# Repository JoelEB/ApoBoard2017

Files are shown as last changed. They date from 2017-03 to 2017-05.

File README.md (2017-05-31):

2017 Propagand-Eye
=======================================
<p align="center">

</p>

This is the development repo for the 2017 Apogaea soldering Workshop project, the Propagand-Eye. 

For all final files for tutorials on how to hack your eyeball, please visit [https://github.com/apoboard](https://github.com/apoboard). 

To donate to this project, please send donations to joeleb on Venmo. 

This board uses an Atmega328p microcontroller (the same device in the Arduino Uno) and can be programmed with an FTDI serial adapter and the Arduino IDE. There is a DC/DC boost-converter (the PAM2401) to provide 5 volts from a single AA battery. On board are 10 addressable WS2812 LEDs (the same LEDs used on all Neopixel products). There is also an infrared (IR) transmitter/receiver pair that allows the boards to communicate with one another. A tactile button is also provided to switch through modes.

License Information
-------------------

All of these files are developed for free, for Apogaea, and for fun. It is publicly available under the GNU General Public License version 2 (the "GPL License"). For more information, please see: http://www.gnu.org/licenses/gpl-2.0.html

Copyright (c) John English, Joel Bartlett, 2017 Licensing: GPL v2

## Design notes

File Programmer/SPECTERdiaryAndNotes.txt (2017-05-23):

getting avrisp mkii working in kali-linux:

copy these rules to a new /etc/udev/avrisp.rules:
SUBSYSTEM!="usb", ACTION!="add", GOTO="avrisp_end"

# Atmel Corp. JTAG ICE mkII
ATTR{idVendor}=="03eb", ATTR{idProduct}=="2103", MODE="660", GROUP="dialout"
# Atmel Corp. AVRISP mkII
ATTR{idVendor}=="03eb", ATTR{idProduct}=="2104", MODE="660", GROUP="dialout"
# Atmel Corp. Dragon
ATTR{idVendor}=="03eb", ATTR{idProduct}=="2107", MODE="660", GROUP="dialout"

LABEL="avrisp_end"

i used nano to do this
root@xfinitywifi:~# nano /etc/udev/avrisp.rules
root@xfinitywifi:~# cd /etc/udev/rules.d/
root@xfinitywifi:/etc/udev/rules.d# ln ../avrisp.rules 60-avrisp.rules
root@xfinitywifi:/etc/udev/rules.d# groups
root
root@xfinitywifi:/etc/udev/rules.d# service udev restart

failed

tried:
apt-get install uisp

and changing SYSFS too ATTR... no that was fine nvm

used this for debugging:
avrdude -c avrispmkII -P usb -p m328 -B 100 -v
ls -lrt /dev/*
dmesg | tail

okay got it to work when I also applied power @ ftdi at same time.
does power have to be provided seperately from avrisp?  That seems silly.
maybe theres an option to turn power pin on.
anyway... i did successfully read the eeprom using:
avrdude -c avrispmkII -P usb -p m328  -U eeprom:r:eepromtestread.hex:i -v -F

now to script it.
i found one python wrapper on github :-)  with a single contributor :-(
https://github.com/theterg/autoavrdude
this is pretty crude shell-parsing stuff... as the author admits.

here's the code:
from subprocess import Popen, PIPE
import threading
import fcntl
import os
import Queue

def setNonBlocking(fd):
    """
    Set the file description of the given file descriptor to non-blocking.
    """
    flags = fcntl.fcntl(fd, fcntl.F_GETFL)
    flags = flags | os.O_NONBLOCK
    fcntl.fcntl(fd, fcntl.F_SETFL, flags)

def reader(fd, queue):
    while True:
        try:
            data = fd.read()
            queue.put(data)
        except IOError:
            continue
        except Exception:
            return

def flushAndWrite(msg, p):
    p.stdout.flush()
    p.stderr.flush()
    p.stdin.write(msg)
    p.stdin.flush()

def writeAndReadResponse(msg, infd, outfd):
    outfd.flush()
    infd.write(msg)
    infd.flush()
    while True:
        try:
            return outfd.read()
        except IOError:
            continue
        except KeyboardInterrupt:
            return ''

def getVtarget(msg):
    lines = msg.split('\n')
    for line in lines:
        if line.startswith('Vtarget'):
            return float(line.split(':')[1][:-2])
    return 0.0

p = Popen("avrdude -c avrispmkii -p m328p -P usb -F -t", shell=True, stdin=PIPE, stdout=PIPE, stderr=PIPE)
setNonBlocking(p.stdout)
setNonBlocking(p.stderr)

#outqueue = Queue.Queue()
#errqueue = Queue.Queue()
#
#outthread = threading.Thread(target=reader, args=(p.stdout, outqueue))
#errthread = threading.Thread(target=reader, args=(p.stderr, errqueue))
#
#outthread.start()
#errthread.start()

*********************** NOTES ABOUT ATMEGA328 FUSES
from the datasheet:
Extended Fuse Byte for ATmega328/328P
Extended Fuse Byte	Bit No	Description				Default Value
BODLEVEL2(1)		2	Brown-out Detector trigger level	1 (unprogrammed)
BODLEVEL1(1)		1	Brown-out Detector trigger level	1 (unprogrammed)
BODLEVEL0(1)		0	Brown-out Detector trigger level	1 (unprogrammed)

High Fuse Byte for ATmega328/328P
High Fuse Byte		Bit No	Description				Default Value
RSTDISBL		7	External Reset Disable			1 (unprogrammed)
DWEN			6	debugWIRE Enable			1 (unprogrammed)
SPIEN			5	Enable Serial Program and Data Download	0 (programmed, SPI programming enabled)
WDTON			4	Watchdog Timer Always On		1 (unprogrammed)
EESAVE			3	EEPROM memory is preserved on erase	1 (unprogrammed), EEPROM not reserved
BOOTSZ1			2	Select Boot Size 			0 (programmed)
BOOTSZ0			1	Select Boot Size			0 (programmed)
BOOTRST			0	Select Reset Vector			1 (unprogrammed)

Low Fuse Byte for ATmega328/328P
Low Fuse Byte		Bit No	Description				Default Value
CKDIV8			7	Divide clock by 8			0 (programmed)
CKOUT			6	Clock output				1 (unprogrammed)
SUT1			5	Select start-up time			1 (unprogrammed)
SUT0			4	Select start-up time			0 (programmed)
CKSEL3			3	Select Clock source			0 (programmed)
CKSEL2			2	Select Clock source			0 (programmed)
CKSEL1			1	Select Clock source			1 (unprogrammed)
CKSEL0			0	Select Clock source			0 (programmed)

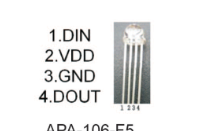
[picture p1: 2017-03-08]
WS2812_LED_Pinout.png

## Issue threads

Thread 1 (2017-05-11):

add A4 or A5 blink in final version of code for pogobed verification

JoelEB, 2017-05-11:
add A4 or A5 blink in final version of code for pogobed verification when programming

spec7er, 2017-05-15:
what code is watching A4/A5?? or is it an LED?  How should it blink? Continuously? Blink once?

JoelEB, 2017-05-15:
I can add this, but I just have a regular LED attached to pin A5 that will blink a few times in setup() to verify the code made it on. But I also added an addressable LED, so we could just use that to see if if starts blinking (each will be random, since the animations will be randomized).

JoelEB, 2017-05-28:
Added 5/28

Closed 2017-05-28.

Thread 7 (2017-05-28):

Error using programmerPi to write_flash

JoelEB, 2017-05-28:
pulled latest. Tested pogo bed on mac using Arduino IDE to burn bootloader and upload test sketch. Verified that all hardware works. Tried on raspberry pi and get this error:
```ApoCmd: write_flash```
```No ATMEGA328 connected```

spec7er, 2017-05-29:
run as root

Closed 2017-05-29.

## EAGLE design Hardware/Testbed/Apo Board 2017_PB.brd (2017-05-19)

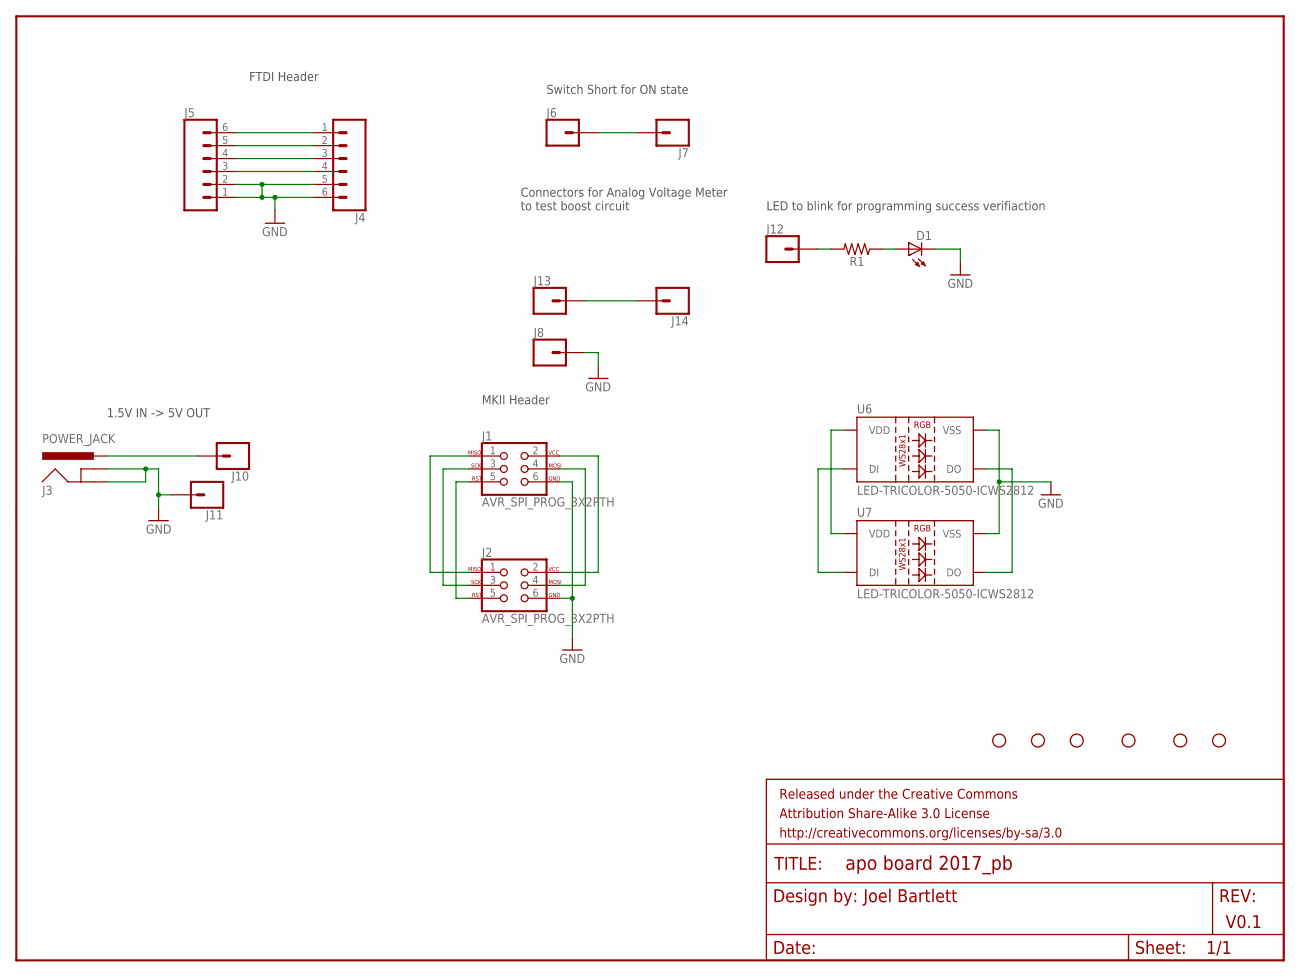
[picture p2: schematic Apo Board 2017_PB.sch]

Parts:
D1: LED5MM
FRAME1: FRAME-LETTER; CREATIVE_COMMONS
H1, H2, H3, H4, H5, H6: STAND-OFF
J1, J2: AVR_SPI_PROG_3X2PTH; 2X3
J3: POWER_JACK; POWER_JACK_PTH
J4, J5: CONN_06LONGPADS; 1X06_LONGPADS
J6, J7, J8, J10, J11, J12, J13, J14: CONN_01PTH_LONGPAD; 1X01_LONGPAD
R1: AXIAL-0.3-KIT
U6, U7: LED-TRICOLOR-5050-ICWS2812; LED-WS2812-THRU

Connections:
GND: D1.K (C), J1.6, J2.6, J3.GND, J3.GNDBREAK, J4.5, J4.6, J5.1, J5.2, J8.1, J11.1, U6.3 (VSS), U7.3 (VSS)
unnamed: J3.PWR, J10.1
unnamed: J1.4, J2.4
unnamed: J1.2, J2.2
unnamed: J1.5, J2.5
unnamed: J1.3, J2.3
unnamed: J1.1, J2.1
unnamed: U6.4 (DO), U7.4 (DO)
unnamed: J4.4, J5.3
unnamed: J4.3, J5.4
unnamed: J4.2, J5.5
unnamed: J4.1, J5.6
unnamed: J6.1, J7.1
unnamed: D1.A, R1.P$1 (1)
unnamed: J12.1, R1.P$2 (2)
unnamed: U6.1 (DI), U7.1 (DI)
unnamed: J13.1, J14.1
unnamed: U6.2 (VDD), U7.2 (VDD)

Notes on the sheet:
Joel Bartlett
V0.1
Switch Short for ON state
FTDI Header
1.5V IN -> 5V OUT
MKII Header
Connectors for Analog Voltage Meter to test boost circuit
LED to blink for programming success verifiaction

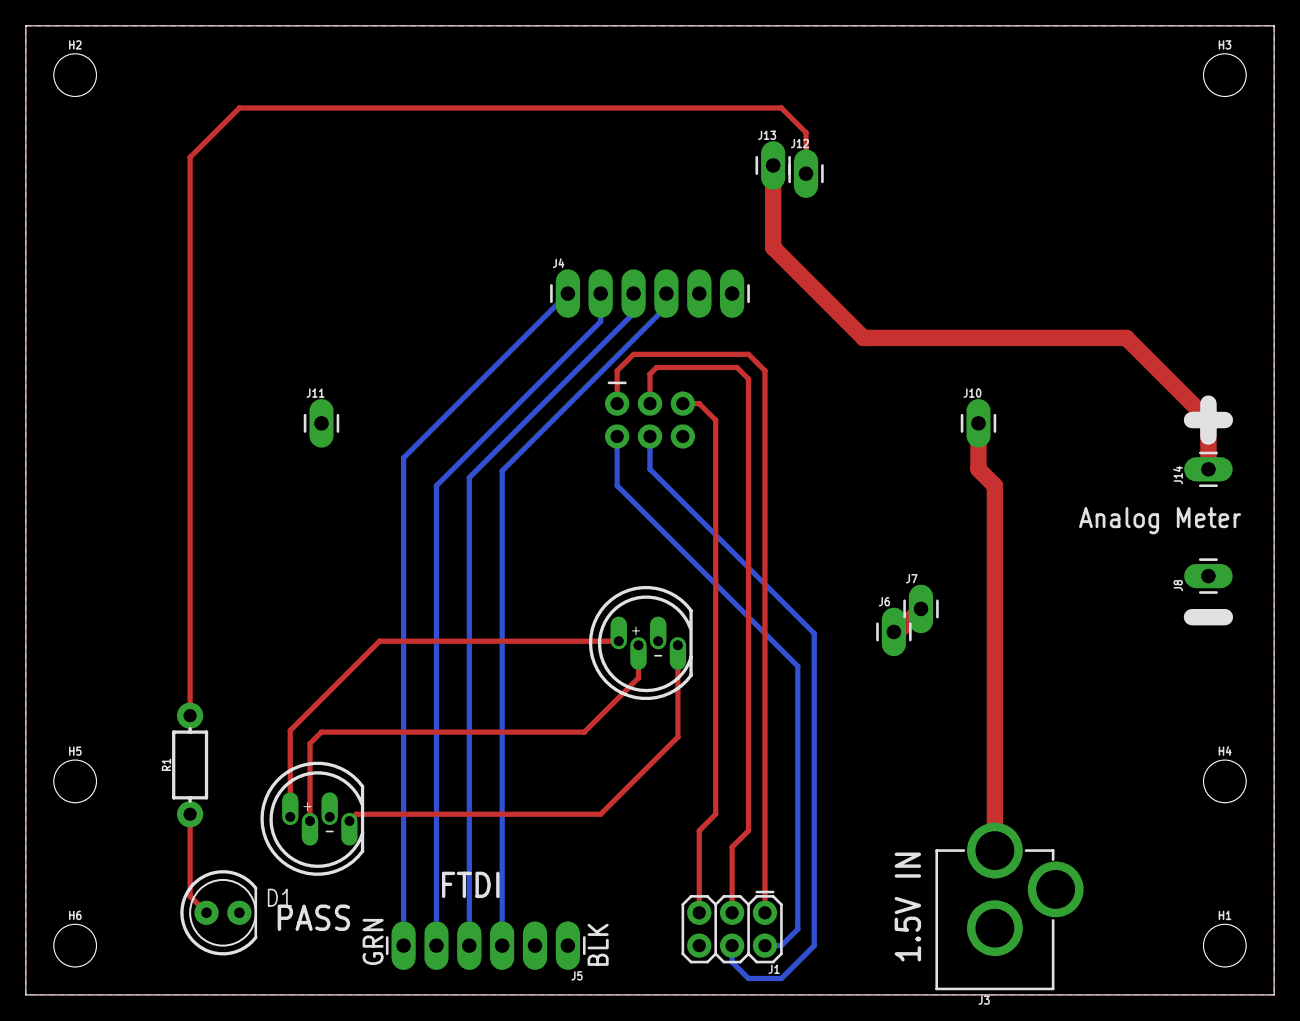
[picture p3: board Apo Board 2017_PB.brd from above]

Board: 2 copper layers, 96.5 x 74.9 mm, 24 parts (1 on the bottom side), 18 nets.

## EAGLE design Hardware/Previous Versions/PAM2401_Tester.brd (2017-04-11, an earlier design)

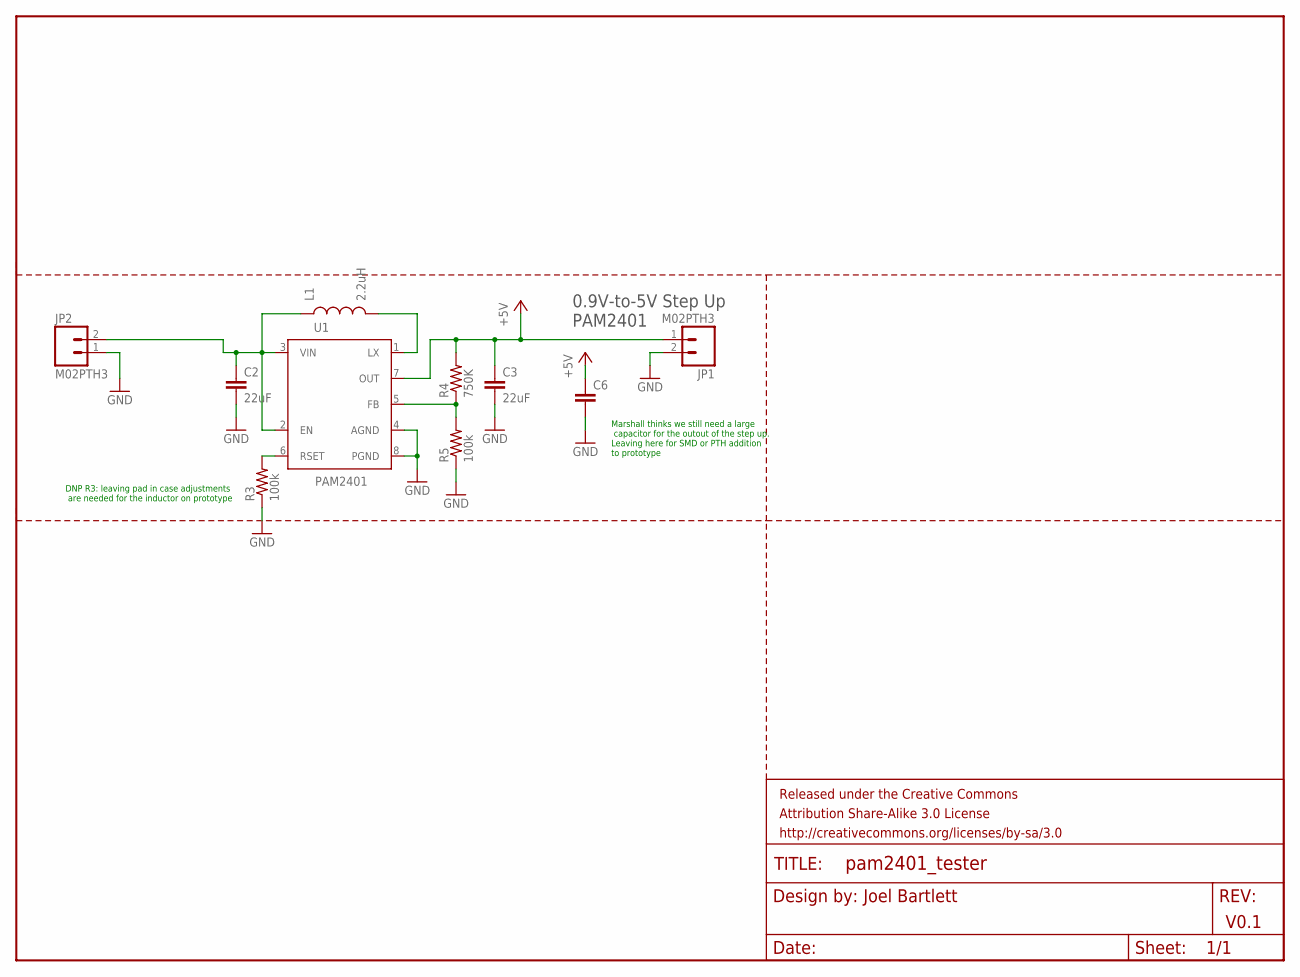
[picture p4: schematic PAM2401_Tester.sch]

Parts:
C2, C3: 22uF; 0805
C6: CAP1206; 1206
FRAME1: FRAME-LETTER; CREATIVE_COMMONS
JP1, JP2: M02PTH3; 1X02_LONGPADS
L1: 2.2uH; CR54
R3, R5: 100k; 0603-RES
R4: 750K; 0603-RES
U1: PAM2401; MSOP8

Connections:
+5V: C3.1, C6.1, JP1.1, R4.2, U1.7 (OUT)
+BATT_RAW: C2.1, JP2.2, L1.P$1 (1), U1.2 (EN), U1.3 (VIN)
GND: C2.2, C3.2, C6.2, JP1.2, JP2.1, R3.1, R5.1, U1.4 (AGND), U1.8 (PGND)
unnamed: R3.2, U1.6 (RSET)
unnamed: L1.P$2 (2), U1.1 (LX)
unnamed: R4.1, R5.2, U1.5 (FB)

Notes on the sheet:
Joel Bartlett
0.9V-to-5V Step Up PAM2401
DNP R3: leaving pad in case adjustments are needed for the inductor on prototype
Marshall thinks we still need a large capacitor for the outout of the step up. Leaving here for SMD or PTH addition to prototype
V0.1

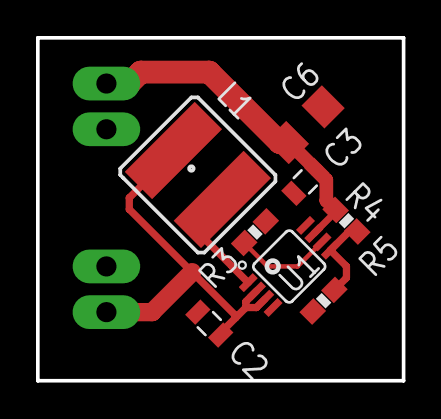
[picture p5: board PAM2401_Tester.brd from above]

Board: 2 copper layers, 20.3 x 19.1 mm, 11 parts (0 on the bottom side), 6 nets.

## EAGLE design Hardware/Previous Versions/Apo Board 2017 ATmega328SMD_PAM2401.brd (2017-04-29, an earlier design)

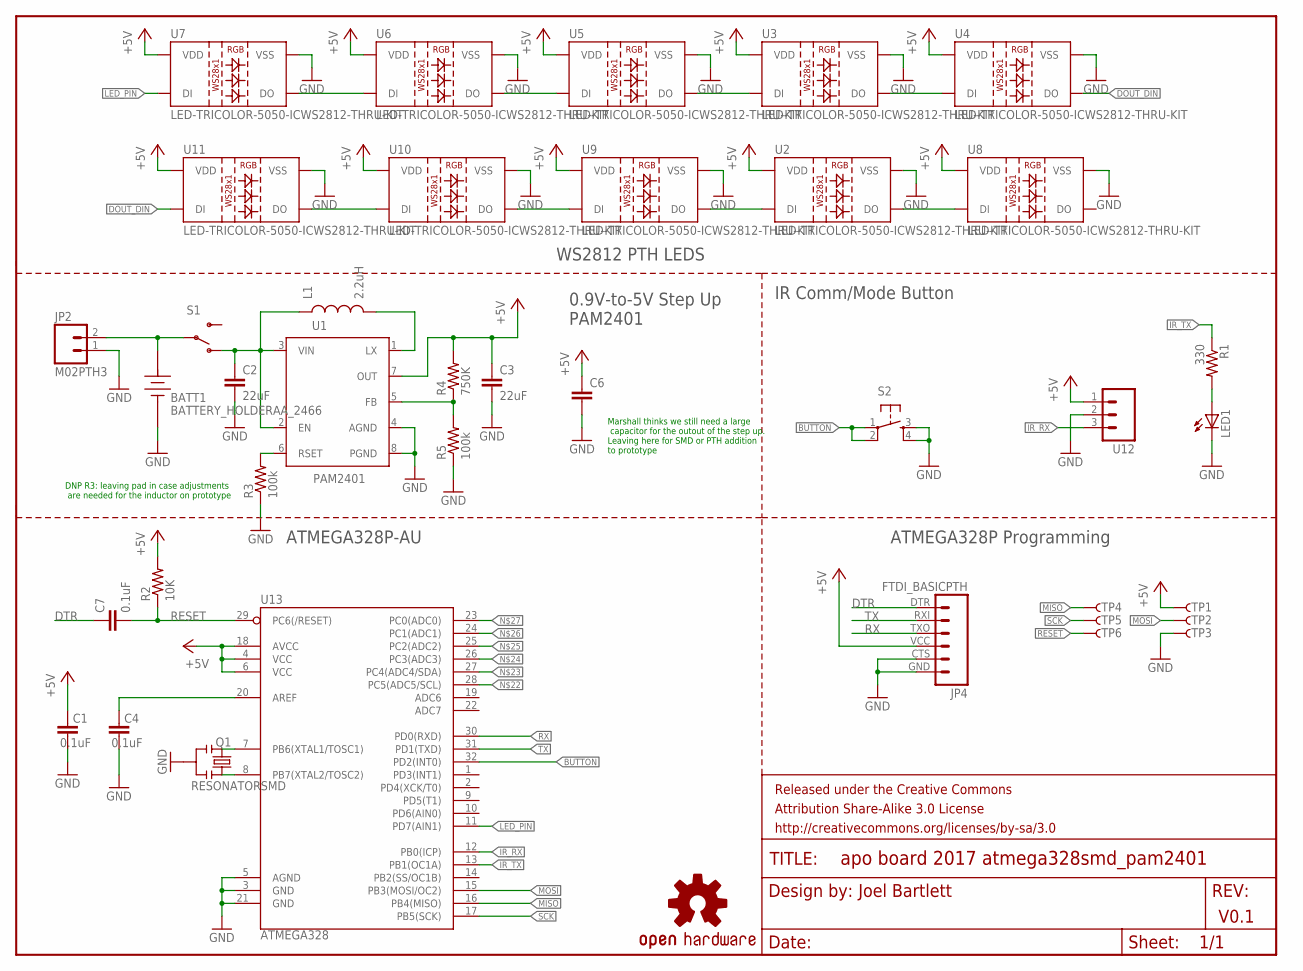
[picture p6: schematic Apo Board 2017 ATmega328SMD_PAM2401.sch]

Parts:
BATT1: BATTERY_HOLDERAA_2466; BATT_HOLDER_AA_2466
C1, C4, C7: 0.1uF; 0402-CAP
C2, C3: 22uF; 0805
C6: CAP1206; 1206
FRAME1: FRAME-LETTER; CREATIVE_COMMONS
JP2: M02PTH3; 1X02_LONGPADS
JP4: FTDI_BASICPTH; FTDI_BASIC
L1: 2.2uH; CR54
LED1: LED5MM-KIT
LOGO1: OSHW-LOGOS; OSHW-LOGO-S
Q1: RESONATORSMD; RESONATOR-SMD
R1: 330; AXIAL-0.3-KIT
R2: 10K; 0402-RES
R3, R5: 100k; 0603-RES
R4: 750K; 0603-RES
S1: SWITCH-SPSTKIT; SWITCH-SPDT_KIT
S2: TAC_SWITCHPTH; TACTILE-PTH
TP1, TP2, TP3, TP4, TP5, TP6: TP-3x5; PAD.03X.05
U1: PAM2401; MSOP8
U2, U3, U4, U5, U6, U7, U8, U9, U10, U11: LED-TRICOLOR-5050-ICWS2812-THRU-KIT; LED-RGB-THRU-KIT
U12: M03IR_RECEIVER; 1X03_IR_RECEIVER
U13: ATMEGA328; TQFP32-08

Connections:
+5V: C1.2, C3.1, C6.1, JP4.VCC (4), R2.2, R4.2, TP1.P$1, U1.7 (OUT), U2.2 (VDD), U3.2 (VDD), U4.2 (VDD), U5.2 (VDD), U6.2 (VDD), U7.2 (VDD), U8.2 (VDD), U9.2 (VDD), U10.2 (VDD), U11.2 (VDD), U12.1, U13.4 (VCC), U13.6 (VCC), U13.18 (AVCC)
+BATT_RAW: BATT1.P, JP2.2, S1.2
AREF: C4.2, U13.20 (AREF)
BUTTON: S2.1, S2.2, U13.32 (PD2(INT0))
DOUT_DIN: U4.4 (DO), U11.1 (DI)
DTR: C7.1, JP4.DTR (1)
GND: BATT1.N, C1.1, C2.2, C3.2, C4.1, C6.2, JP2.1, JP4.CTS (5), JP4.GND (6), LED1.K (C), Q1.2, R3.1, R5.1, S2.3, S2.4, TP3.P$1, U1.4 (AGND), U1.8 (PGND), U2.3 (VSS), U3.3 (VSS), U4.3 (VSS), U5.3 (VSS), U6.3 (VSS), U7.3 (VSS), U8.3 (VSS), U9.3 (VSS), U10.3 (VSS), U11.3 (VSS), U12.2, U13.3 (GND), U13.5 (AGND), U13.21 (GND)
IR_RX: U12.3, U13.12 (PB0(ICP))
IR_TX: R1.P$1 (1), U13.13 (PB1(OC1A))
LED_PIN: U7.1 (DI), U13.11 (PD7(AIN1))
MISO: TP4.P$1, U13.16 (PB4(MISO))
MOSI: TP2.P$1, U13.15 (PB3(MOSI/OC2))
unnamed: U6.1 (DI), U7.4 (DO)
unnamed: U5.1 (DI), U6.4 (DO)
unnamed: LED1.A, R1.P$2 (2)
unnamed: R3.2, U1.6 (RSET)
unnamed: U3.1 (DI), U5.4 (DO)
unnamed: U3.4 (DO), U4.1 (DI)
unnamed: L1.P$2 (2), U1.1 (LX)
unnamed: U10.1 (DI), U11.4 (DO)
unnamed: C2.1, L1.P$1 (1), S1.1 (O), U1.2 (EN), U1.3 (VIN)
unnamed: U9.1 (DI), U10.4 (DO)
unnamed: R4.1, R5.2, U1.5 (FB)
unnamed: U2.1 (DI), U9.4 (DO)
unnamed: U2.4 (DO), U8.1 (DI)
unnamed: Q1.1, U13.8 (PB7(XTAL2/TOSC2))
unnamed: Q1.3, U13.7 (PB6(XTAL1/TOSC1))
RESET: C7.2, R2.1, TP6.P$1, U13.29 (PC6(/RESET))
RX: JP4.TXO (3), U13.30 (PD0(RXD))
SCK: TP5.P$1, U13.17 (PB5(SCK))
TX: JP4.RXI (2), U13.31 (PD1(TXD))

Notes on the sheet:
Joel Bartlett
WS2812 PTH LEDS
0.9V-to-5V Step Up PAM2401
IR Comm/Mode Button
ATMEGA328P-AU
ATMEGA328P Programming
DNP R3: leaving pad in case adjustments are needed for the inductor on prototype
Marshall thinks we still need a large capacitor for the outout of the step up. Leaving here for SMD or PTH addition to prototype
V0.1

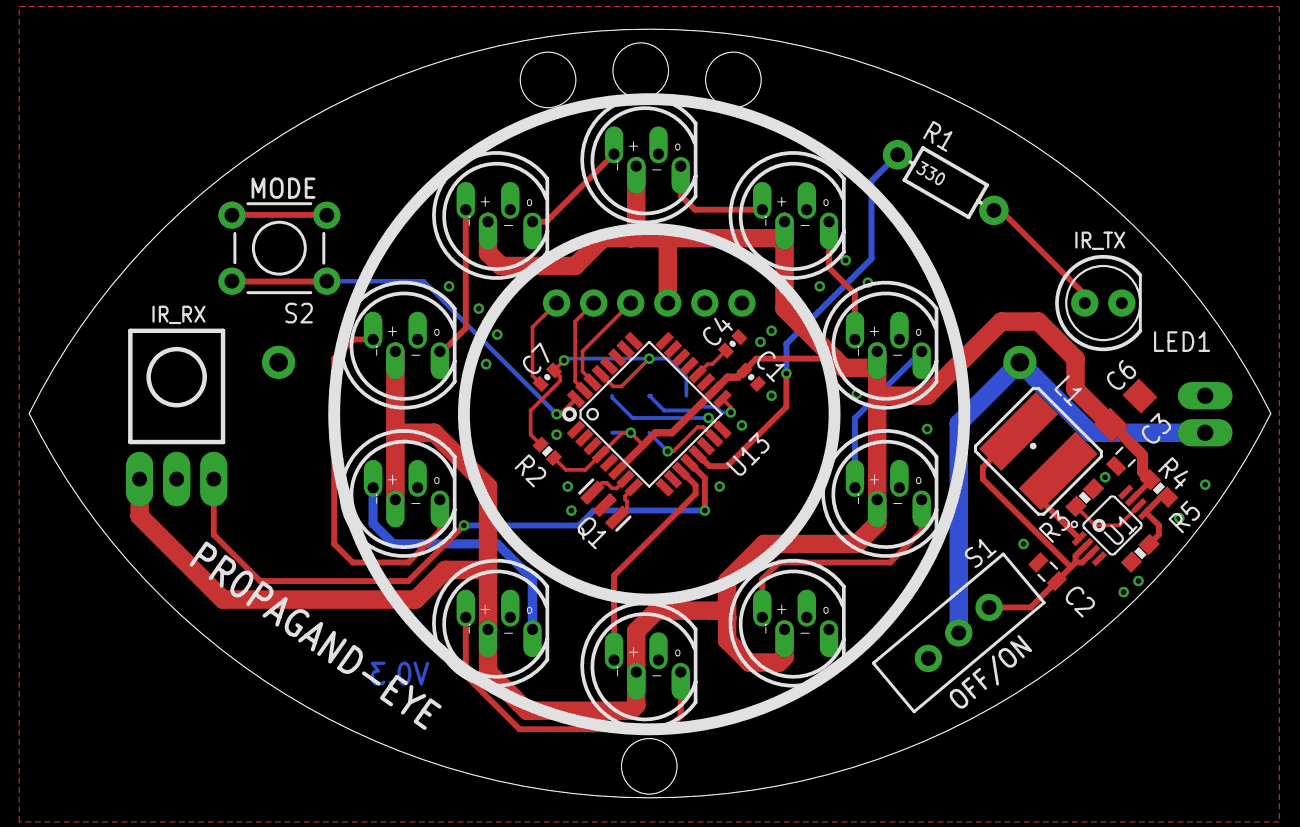
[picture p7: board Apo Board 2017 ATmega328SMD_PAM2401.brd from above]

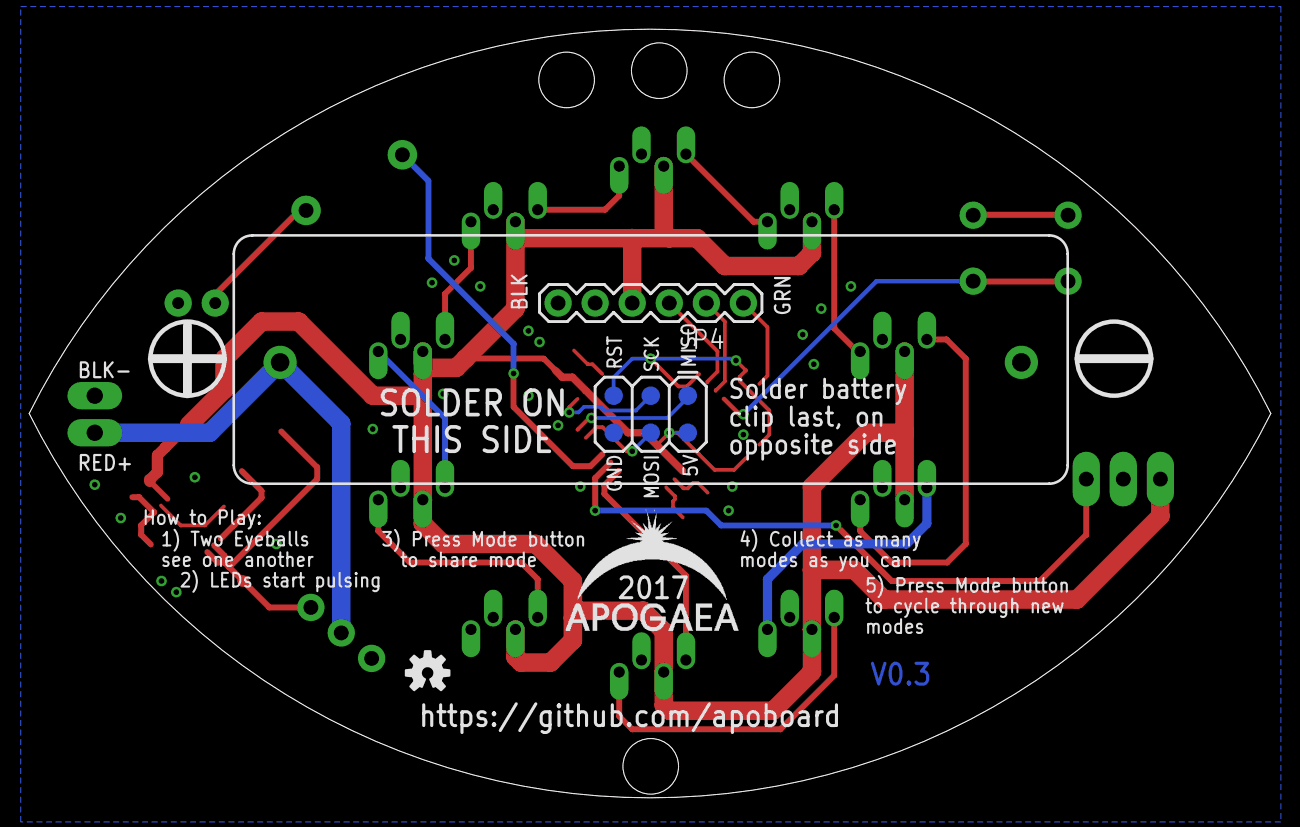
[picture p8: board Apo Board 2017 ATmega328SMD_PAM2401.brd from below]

Board: 2 copper layers, 85.1 x 52.7 mm, 41 parts (10 on the bottom side), 31 nets.

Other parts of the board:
U$2: APOLOGO

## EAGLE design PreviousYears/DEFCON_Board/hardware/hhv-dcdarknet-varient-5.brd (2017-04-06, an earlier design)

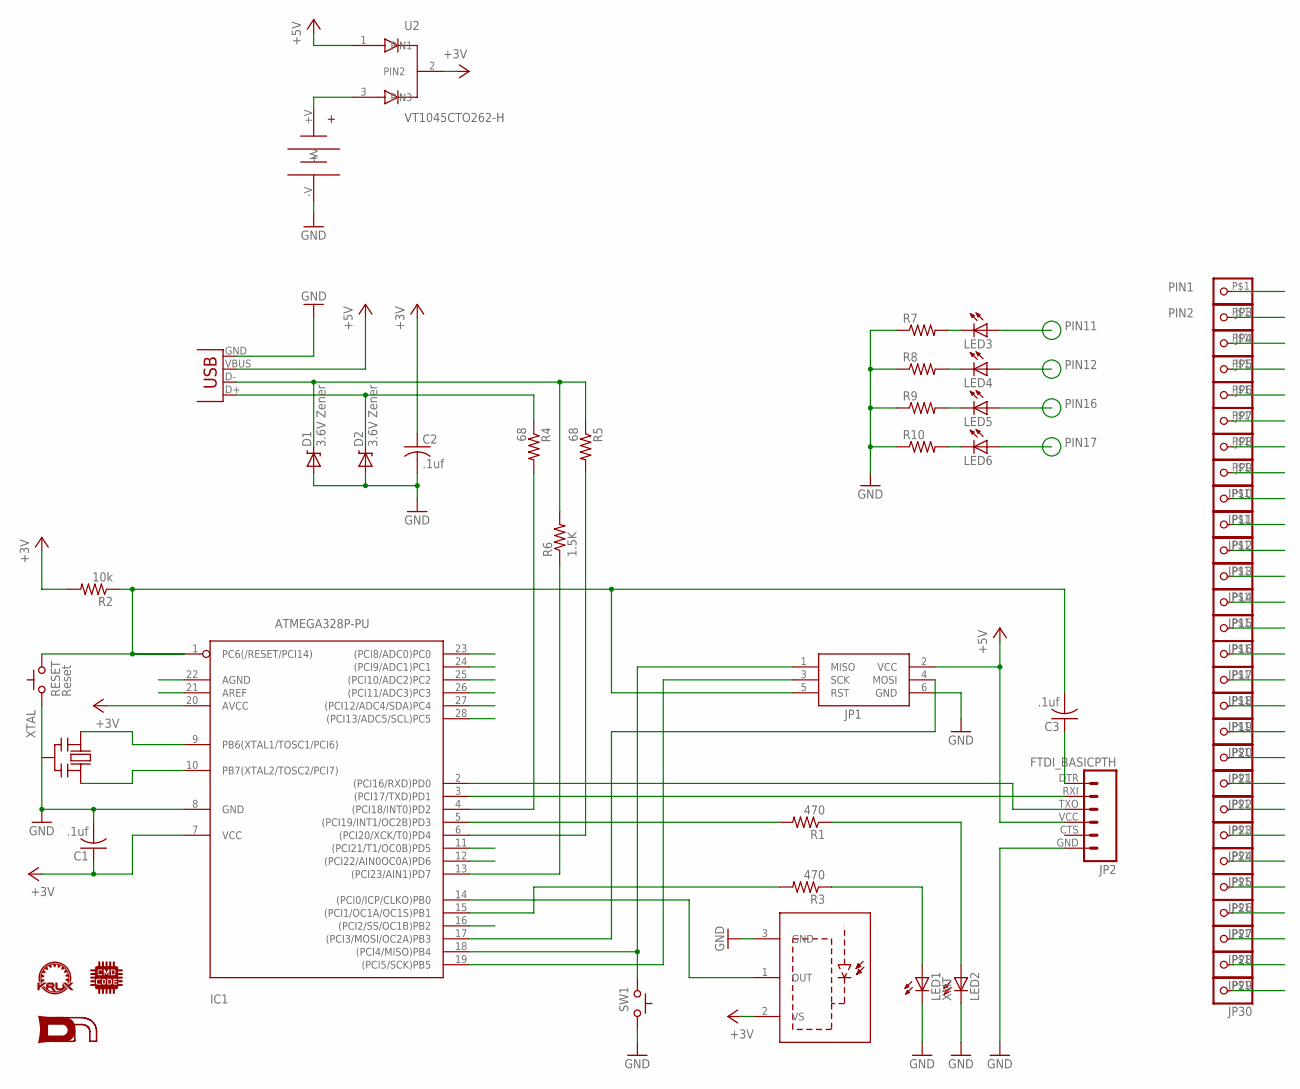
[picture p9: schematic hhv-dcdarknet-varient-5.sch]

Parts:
C1, C2, C3: .1uf; C025-030X050
D1, D2: 3.6V Zener; DIODE-ZENER
IC1: ATMEGA328P-PU; DIL28-3
JP1: JP1; AVRISP
JP2: FTDI_BASICPTH; FTDI_BASIC
JP3, JP4, JP5, JP6, JP7, JP8, JP9, JP10, JP11, JP12, JP13, JP14, JP15, JP16, JP17, JP18, JP19, JP20, JP21, JP22, JP23, JP24, JP25: PINHD-1X11X1_SQUARE; 1X1-SMALL_CUT
JP26, JP27, JP28, JP29, JP30: PINHD-1X11X1-SMALL; 1X1-SMALL
LED1: XMT; LED5MM-FLAT
LED2: LED5MM-FLAT
LED3, LED4, LED5, LED6: LED1206; LED-1206
R1, R3: 470; AXIAL-0.3
R2: 10k; AXIAL-0.3
R4, R5: 68; AXIAL-0.3
R6: 1.5K; AXIAL-0.3
R7, R8, R9, R10: RESISTOR1206; 1206
RESET: Reset; TACTILE-2PIN
SW1: SWITCH_TACTILETACTILE-2PIN; TACTILE-2PIN
U1: RCV; IR-MODULE
U2: VT1045CTO262-H; TO262-H
U$1: DN_LOGO
U$2: CMDC0DE_LOGO; CMDC0DE
U$3: KRUX_LOGO
U$5: 12BH423-GR3-CELL_NOBORDER; 3-AAA-CELL_NOBORDER
X2: USB; USB-B-PTH
XTAL: CERMOSCILL-THM; CERM_OSC

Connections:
+3V3: C1.1, C2.1, IC1.7 (VCC), IC1.20 (AVCC), JP9.P$1, JP22.P$1, R2.P$2 (2), U1.2 (VS), U2.2 (PIN2)
+5V: JP1.2 (VCC), JP2.VCC (4), U2.1 (PIN1), X2.VBUS
GND: C1.2, C2.2, D1.P$2 (A), D2.P$2 (A), IC1.8 (GND), JP1.6 (GND), JP2.GND (6), JP10.P$1, LED1.K (C), LED2.K (C), R7.1, R8.1, R9.1, R10.1, RESET.P$2 (C), SW1.P$1 (A), U1.3 (GND), U$5.-V, X2.GND, XTAL.P$2 (GND)
unnamed: C3.1, JP2.DTR (1)
unnamed: LED3.C, R7.2
unnamed: LED4.C, R8.2
unnamed: LED5.C, R9.2
unnamed: LED6.C, R10.2
unnamed: LED1.A, R3.P$1 (1)
unnamed: LED2.A, R1.P$1 (1)
unnamed: D2.P$1 (C), R4.P$1 (1), X2.D+
unnamed: U2.3 (PIN3), U$5.+V
PIN1: C3.2, IC1.1 (PC6(/RESET/PCI14)), JP1.5 (RST), JP3.P$1, R2.P$1 (1), RESET.P$1 (A)
PIN2: IC1.2 ((PCI16/RXD)PD0), JP2.TXO (3), JP4.P$1
PIN3: IC1.3 ((PCI17/TXD)PD1), JP2.RXI (2), JP5.P$1
PIN4: IC1.4 ((PCI18/INT0)PD2), JP6.P$1, R4.P$2 (2)
PIN5: IC1.5 ((PCI19/INT1/OC2B)PD3), JP7.P$1, R1.P$2 (2)
PIN6: IC1.6 ((PCI20/XCK/T0)PD4), JP8.P$1, R5.P$2 (2)
PIN9: IC1.9 (PB6(XTAL1/TOSC1/PCI6)), JP11.P$1, XTAL.P$1 (IN)
PIN10: IC1.10 (PB7(XTAL2/TOSC2/PCI7)), JP12.P$1, XTAL.P$3 (OUT)
PIN11: IC1.11 ((PCI21/T1/OC0B)PD5), JP13.P$1, LED3.A
PIN12: IC1.12 ((PCI22/AIN0OC0A)PD6), JP14.P$1, LED4.A
PIN13: IC1.13 ((PCI23/AIN1)PD7), JP15.P$1, R6.P$1 (1)
PIN14: IC1.14 ((PCI0/ICP/CLKO)PB0), JP16.P$1, U1.1 (OUT)
PIN15: IC1.15 ((PCI1/OC1A/OC1S)PB1), JP17.P$1, R3.P$2 (2)
PIN16: IC1.16 ((PCI2/SS/OC1B)PB2), JP18.P$1, LED5.A
PIN17: IC1.17 ((PCI3/MOSI/OC2A)PB3), JP1.4 (MOSI), JP19.P$1, LED6.A
PIN18: IC1.18 ((PCI4/MISO)PB4), JP1.1 (MISO), JP20.P$1, SW1.P$2 (C)
PIN19: IC1.19 ((PCI5/SCK)PB5), JP1.3 (SCK), JP21.P$1
PIN21: IC1.21 (AREF), JP23.P$1
PIN22: IC1.22 (AGND), JP24.P$1
PIN23: IC1.23 ((PCI8/ADC0)PC0), JP25.P$1
PIN24: IC1.24 ((PCI9/ADC1)PC1), JP26.P$1
PIN25: IC1.25 ((PCI10/ADC2)PC2), JP27.P$1
PIN26: IC1.26 ((PCI11/ADC3)PC3), JP28.P$1
PIN27: IC1.27 ((PCI12/ADC4/SDA)PC4), JP29.P$1
PIN28: IC1.28 ((PCI13/ADC5/SCL)PC5), JP30.P$1
USB: D1.P$1 (C), R5.P$1 (1), R6.P$2 (2), X2.D-

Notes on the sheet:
PIN11
PIN12
PIN16
PIN17

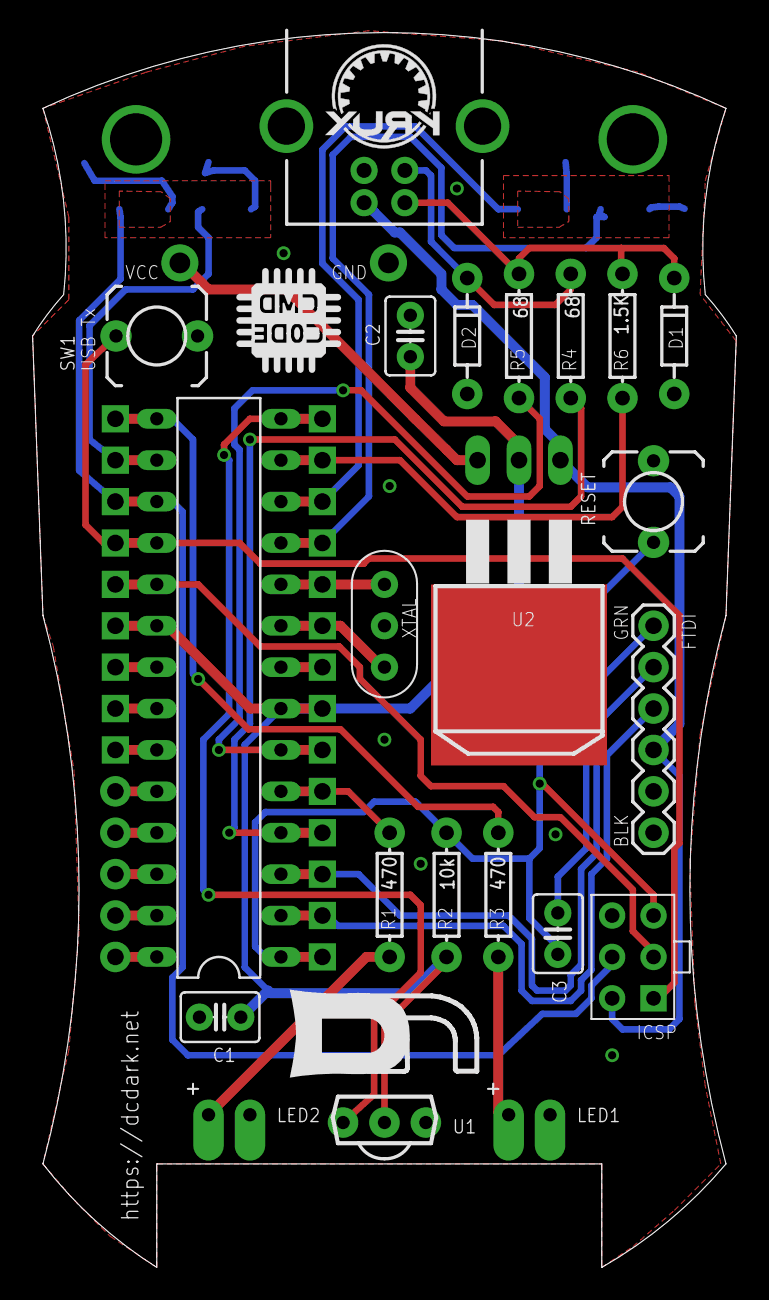
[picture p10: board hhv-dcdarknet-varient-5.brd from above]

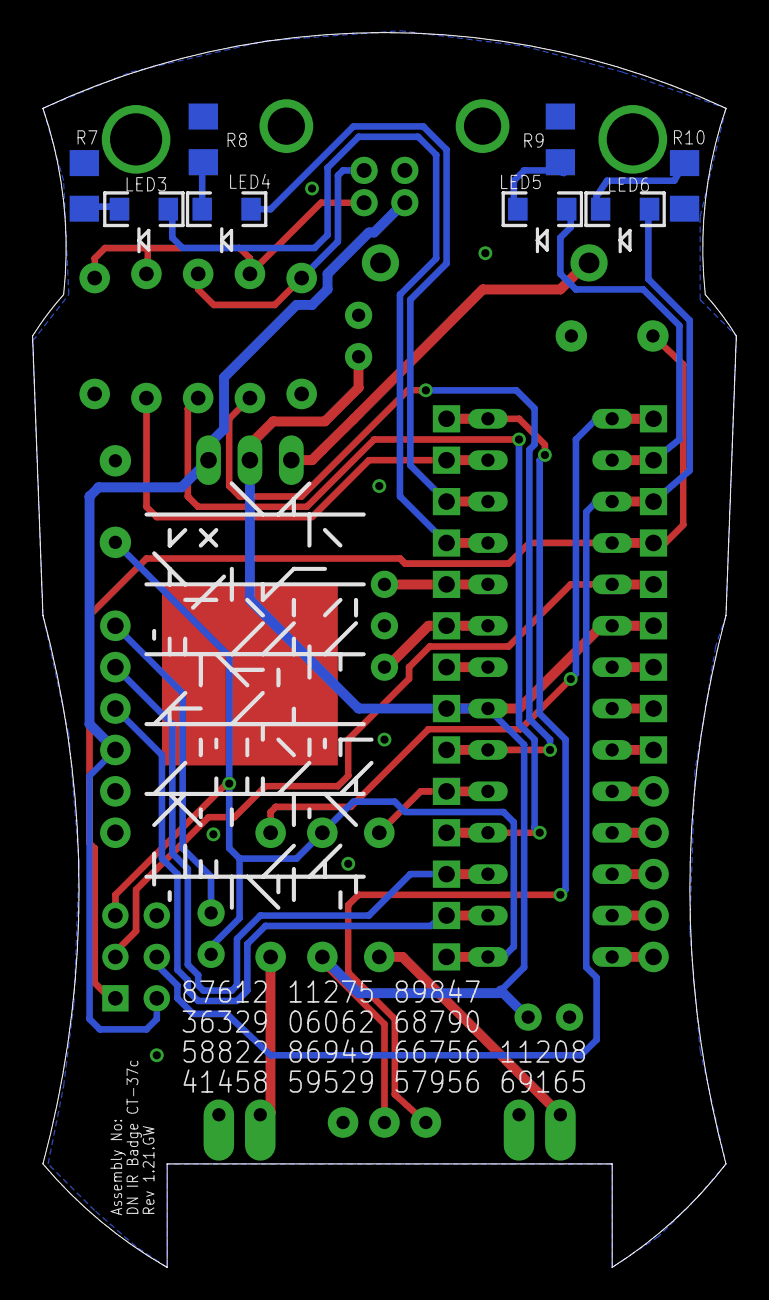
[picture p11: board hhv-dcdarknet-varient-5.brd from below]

Board: 2 copper layers, 43.2 x 75.8 mm, 62 parts (10 on the bottom side), 38 nets.

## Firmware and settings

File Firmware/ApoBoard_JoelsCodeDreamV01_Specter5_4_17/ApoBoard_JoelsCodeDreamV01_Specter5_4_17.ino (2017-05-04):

#include <stdlib.h>

#include <avr/pgmspace.h>

#include <EEPROM.h>
#include <avr/sleep.h>
#include <Wire.h>
#include <Adafruit_NeoPixel.h>
#include <avr/power.h> // Comment out this line for non-AVR boards (Arduino Due, etc.)
#include "IRSerial-2014.h"

#define NeoPIN 7// was 10
#define NeoLEDs 10 //was 10 //number of addressable LEDs
#define NumEffects 10
#define BUTTON_PIN 2
#define debounce_time 10 // button debounce in ms
// IR Parameters
#define IR_RX 8 //was 8
#define IR_TX 9 //was 9
#define IR_BAUD 300
IRSerial irSerial(IR_RX, IR_TX, false, true);

#define SERIAL_BAUD 115200

/////////// GLOBALS /////////////////
bool button_shadow = false;
int button = BUTTON_PIN;
int photopot = A1;
int colorModeMax = 5;
int colorMode = 0;

uint8_t brightness = 40; //global brightness


uint8_t BGcounter = 0; //global for Background color counter
uint8_t FGcounter = 0; //global for Foreground color counter

#define PUSHED false
#define NOT_PUSHED true
#define WATCH_BUTTON true
#define IGNORE_BUTTON false
const int buttonWaitInterval = 6000;
unsigned long previousMicros = 0;
boolean previousButtonState = NOT_PUSHED;
boolean debouncedButtonState = NOT_PUSHED;
boolean bounceState = false;


class Colorsets {
  public:
    uint32_t colorarray [NumEffects] [8] = {
      {0xFF0000, 0x00FF00, 0x0000FF, 0x00FFFF,     0, 0, 0, 0}, //coder colorz
      {0xFF3377, 0x119933, 0x220044, 0x880044,     0x110022, 0x440022, 0x771133, 0x004411}, //coder colorz
      {0xFF3377, 0x119933, 0x220044, 0x880044,     0x080011, 0x003311, 0x110811, 0x002208}, //coder colorz
      {0x00FF00, 0x00FF00, 0x00FF00, 0x00FF00,     0x000200, 0x000200, 0x000200, 0x000200} //RED only
    };

    uint32_t getFG(uint8_t colorsetnum, int8_t FGdelta) {
      FGcounter += FGdelta;
      return (colorarray[colorsetnum] [FGcounter % 4]);
    }
    uint32_t getBG(uint8_t colorsetnum, int8_t BGdelta) {
      BGcounter += BGdelta;
      return (colorarray[colorsetnum] [4 + BGcounter % 4]);
    }
};


class Neo_event {
  public:

    int8_t event_type [NeoLEDs];
    uint8_t init_r [NeoLEDs];
    uint8_t init_g [NeoLEDs];
    uint8_t init_b [NeoLEDs];
    uint8_t end_r [NeoLEDs];
    uint8_t end_g [NeoLEDs];
    uint8_t end_b [NeoLEDs];
    int8_t diff_r [NeoLEDs];
    int8_t diff_g [NeoLEDs];
    int8_t diff_b [NeoLEDs];
    uint16_t event_duration [NeoLEDs];
    long unsigned int event_starttime [NeoLEDs];
    uint8_t current_r[NeoLEDs], current_g[NeoLEDs], current_b[NeoLEDs];

    static const int8_t
    event_setcolor = 0x10,
    event_fadeto = 0x20,
    event_wait = 0xF0;

    boolean setcolor(uint8_t LEDnum, uint32_t Color) {
      LEDnum %= NeoLEDs;
      event_type[LEDnum] = event_setcolor;
      init_g[LEDnum] = (Color >> 17) & 0x7F;
      init_r[LEDnum] = (Color >> 9) & 0x7F;
      init_b[LEDnum] = (Color >> 1) & 0x7F;
    }

    boolean fadeto(uint8_t LEDnum, uint32_t Color, uint16_t duration) {
      LEDnum %= NeoLEDs;
      event_type[LEDnum] = event_fadeto;
      end_g[LEDnum] = (Color >> 17) & 0x7F;
      end_r[LEDnum] = (Color >> 9) & 0x7F;
      end_b[LEDnum] = (Color >> 1) & 0x7F;
      init_r[LEDnum] = current_r[LEDnum];
      init_g[LEDnum] = current_g[LEDnum];
      init_b[LEDnum] = current_b[LEDnum];

      diff_g[LEDnum] = end_g[LEDnum] - init_g[LEDnum];
      diff_r[LEDnum] = end_r[LEDnum] - init_r[LEDnum];
      diff_b[LEDnum] = end_b[LEDnum] - init_b[LEDnum];
      /*Serial.print("fadeto: [");
        Serial.print(LEDnum);
        Serial.print("] ");
        Serial.print(init_g[LEDnum],HEX);
        Serial.print(" -> ");
        Serial.println(end_g[LEDnum],HEX);*/
      event_starttime[LEDnum] = millis();
      event_duration[LEDnum] = duration;
    }

    uint8_t applybrightness(uint8_t in, uint8_t intensity) {

      return (uint16_t) (in * intensity) / 100;
    }

    
    ////////////////////////////////////////////////////////
    ////////////////////////////////////////////////////////
    boolean wait(int waitfor, Adafruit_NeoPixel &strip ) {
      waitfor = waitfor > 0 ? waitfor : 0;
      uint32_t returnTime = millis() + waitfor;
      uint32_t out_color;
      for (int i = 0; i < NeoLEDs; i++) {
        switch (event_type[i]) {
          case event_setcolor :
            event_type[i] = 0;
            out_color = (((uint32_t) init_g[i]) << 16) + (((uint16_t) init_r[i]) << 8) + init_b[i];
            strip.setPixelColor(i, out_color) ;
            break;

          case event_fadeto :
            event_type[i] = -event_fadeto;
            break;
        }
      }
      strip.show();
      while (millis() < returnTime) {
        updateButton();

        for (int i = 0; i < NeoLEDs; i++) {
          int32_t eventprogress  = millis() - event_starttime[i];

          switch (event_type[i]) {
            case -event_fadeto :
              if (eventprogress < event_duration[i]) {
                current_r[i] = init_r[i] + (eventprogress * diff_r[i]) / event_duration[i];
                current_g[i] = init_g[i] + (eventprogress * diff_g[i]) / event_duration[i];
                current_b[i] = init_b[i] + (eventprogress * diff_b[i]) / event_duration[i];
              }
              else {
                init_r[i] = end_r[i];
                current_r[i] = end_r[i];
                init_g[i] = end_g[i];
                current_g[i] = end_g[i];
                init_b[i] = end_b[i];
                current_b[i] = end_b[i];
                event_type[i] = 0;
              }
              /*strip.setPixelColor(i, strip.Color(
                  applybrightness(current_g[i],brightness),
                  applybrightness(current_r[i],brightness),
                  applybrightness(current_b[i],brightness)
                  ));*/
              strip.setPixelColor(i, strip.Color(
                                    current_g[i],
                                    current_r[i],
                                    current_b[i]
                                  ));
              /*
                Serial.print(i);
                Serial.print(": ");
                Serial.print(end_g[i] - init_g[i],HEX);
                Serial.print(", ");
                Serial.print(diff_g[i],HEX);
                Serial.print(", ");
                Serial.println(current_g[i],HEX);
                delay(10); //slow down serial output
              */
              break;
          }
        }
        strip.show();
      }
    }


    void updateButton() {
     if (bounceState == WATCH_BUTTON) {
        boolean currentButtonState = digitalRead(BUTTON_PIN);
        if (previousButtonState != currentButtonState) {
          bounceState = IGNORE_BUTTON;
          previousMicros = micros();
        }
        previousButtonState = currentButtonState;
      }
      if (bounceState == IGNORE_BUTTON) {
        unsigned long currentMicros = micros();
        if ((unsigned long)(currentMicros - previousMicros) >= buttonWaitInterval) {
          debouncedButtonState = digitalRead(BUTTON_PIN);
          bounceState = WATCH_BUTTON;
        }
      }
    }

};


//-------------------------------------------------------------------------------------------------

Adafruit_NeoPixel strip = Adafruit_NeoPixel(NeoLEDs, NeoPIN, NEO_GRB + NEO_KHZ800);

// Main morse LED
#define LED_PIN 3




//BEGIN GLOBAL VARS:
//We are getting tight on space so I'm packing variables as tightly as I can
struct _PackedVars {
  /*  uint32_t InSerialEpic : 1;
    uint32_t AwaitingSerialAnswer: 1;
    uint32_t DisplayAnswer:1;
    uint32_t LEDMode : 4; //what start up mode are we need (animation)
    uint32_t Silent : 1;
    uint32_t LINE1Loc : 6;
    uint32_t AnswerPos : 4;
    uint32_t hasSilk1 : 1;
    uint32_t hasSilk2 : 1;
    uint32_t hasSilk3 : 1;
    uint32_t isContestRunner : 1;
  */
  uint32_t AwaitingSerialAnswer: 1;
  uint32_t DisplayAnswer: 1;
  uint32_t LEDMode : 4; //what start up mode are we need (animation)
  uint32_t swapKeyAndGUID : 1;
  uint32_t modeInit : 1;
} PackedVars;

uint16_t KEY[4];
char GUID[9] = "201005xx";
unsigned long nextBeacon;
#define OLED_RESET 4
//DarkNetDisplay Display(OLED_RESET);
//END GLOBAL VARS




#define ENDLINE F("\n")

//experimental
uint32_t PUF_hash()
{
  uint8_t const * p;
  uint8_t i;
  uint16_t hash = 0;
  
  uint8_t hash0 = 0;
  uint8_t hash1 = 0;
  
  p = (const uint8_t *)(0x8000);//was (8192 - 256);
  i = 0;
  do
  {
    hash0 ^= *p;
    p ++;
    hash1 ^= *p;
    p ++;
    i ++;
  }
  while ( i != 0 );
  hash = hash0 + (hash1 << 8);
  
  Serial.begin(115200);
  Serial.println(hash0,HEX);
  Serial.println(hash1,HEX);
  
  return (hash);
}



// Morse Code constants
unsigned char const morse[28] PROGMEM = {
  0x05,   // A  .-     00000101
  0x18,   // B  -...   00011000
  0x1A,   // C  -.-.   00011010
  0x0C,   // D  -..    00001100
  0x02,   // E  .      00000010
  0x12,   // F  ..-.   00010010
  0x0E,   // G  --.    00001110
  0x10,   // H  ....   00010000
  0x04,   // I  ..     00000100
  0x17,   // J  .---   00010111
  0x0D,   // K  -.-    00001101
  0x14,   // L  .-..   00010100
  0x07,   // M  --     00000111
  0x06,   // N  -.     00000110
  0x0F,   // O  ---    00001111
  0x16,   // P  .--.   00010110
  0x1D,   // Q  --.-   00011101
  0x0A,   // R  .-.    00001010
  0x08,   // S  ...    00001000
  0x03,   // T  -      00000011
  0x09,   // U  ..-    00001001
  0x11,   // V  ...-   00010001
  0x0B,   // W  .--    00001011
  0x19,   // X  -..-   00011001
  0x1B,   // Y  -.--   00011011
  0x1C,   // Z  --..   00011100
  0x01,   // space     00000001
  0x5A,   // @  .--.-. 01011010
};

//debugging macros
//#define SERIAL_TRACE
#ifdef SERIAL_TRACE
#define SERIAL_TRACE_LN(a) Serial.println(a);
#define SERIAL_TRACE(a) Serial.print(a);
#else
#define SERIAL_TRACE_LN(a)
#define SERIAL_TRACE(a)
#endif

//#define SERIAL_INFO
#ifdef SERIAL_INFO
#define SERIAL_INFO_LN(a) Serial.println(a);
#define SERIAL_INFO(a) Serial.print(a);
#else
#define SERIAL_INFO_LN(a)
#define SERIAL_INFO(a)
#endif
//end debugging macros



void readContestRunnerKeyAndGUID() {
#if MAKE_ME_A_CONTEST_RUNNER //make contest runner badge
  // Pull GUID and Private key from EEPROM
  for (char ndx = 0; ndx < 8; ndx++) {
    GUID[ndx] = EEPROM.read(UBER_CRYTPO_CONTEST_RUNNER_ADDR + 8 + ndx);
  }
  GUID[8] = 0;
  // Yes, this is big endian. I don't want to have to byte-swap
  // when building the EEPROM file from text strings.
  KEY[0] = (EEPROM.read(UBER_CRYTPO_CONTEST_RUNNER_ADDR + 0) << 8) + EEPROM.read(UBER_CRYTPO_CONTEST_RUNNER_ADDR + 1);
  KEY[1] = (EEPROM.read(UBER_CRYTPO_CONTEST_RUNNER_ADDR + 2) << 8) + EEPROM.read(UBER_CRYTPO_CONTEST_RUNNER_ADDR + 3);
  KEY[2] = (EEPROM.read(UBER_CRYTPO_CONTEST_RUNNER_ADDR + 4) << 8) + EEPROM.read(UBER_CRYTPO_CONTEST_RUNNER_ADDR + 5);
  KEY[3] = (EEPROM.read(UBER_CRYTPO_CONTEST_RUNNER_ADDR + 6) << 8) + EEPROM.read(UBER_CRYTPO_CONTEST_RUNNER_ADDR + 7);
#endif
}

/*
  void readInGUIDAndKey() {
  for (char ndx = 0; ndx < 8; ndx++) {
    GUID[ndx] = EEPROM.read(GUID_ADDR + ndx);
  }
  GUID[8] = 0;
  // Yes, this is big endian. I don't want to have to byte-swap
  // when building the EEPROM file from text strings.
  KEY[0] = (EEPROM.read(KEY_ADDR + 0) << 8) + EEPROM.read(KEY_ADDR + 1);
  KEY[1] = (EEPROM.read(KEY_ADDR + 2) << 8) + EEPROM.read(KEY_ADDR + 3);
  KEY[2] = (EEPROM.read(KEY_ADDR + 4) << 8) + EEPROM.read(KEY_ADDR + 5);
  KEY[3] = (EEPROM.read(KEY_ADDR + 6) << 8) + EEPROM.read(KEY_ADDR + 7);
  }
*/

/* This is the workhorse function.  Whatever you do elsewhere,
   When you're not working you need to call this so it looks
   for IR data and acts on it if received.  The Rx ISR has a
   64 byte buffer, so you need to call this at least once every
   (1 sec/300 symbols * 10 symbos/1 byte * 64 byte buffer = )
   2.13 seconds before you risk overflowing the buffer, but I'd
   make sure you call it more often than that.  Basically,
   whenever you are pausing, use this instead of delay().

   Like delay(), but looks for IR serial data while waiting.
   Delays for pauseFor milliseconds.  Tight koops around looking
   for serial data.  Also triggers a USB dump if the button is
   pressed.

   IMPORTANT: If either a full Serial frame is received, or the
   button is pressed, then delayAndReadIR() can delay for much
   longer than pauseFor milliseconds as it either handles the USB,
   or handles a received IR signal.
*/

// Sends our GUID out over the IR.  Call this "often"
// when it's convenient in your animation. It'll handle
// dealing with the timing, whether it's been long enough
// to send another beacon.
void beaconGUID(int timegap) {
  if (millis() >= nextBeacon) {
    /*if (1 == PackedVars.swapKeyAndGUID) {
      readContestRunnerKeyAndGUID();
      }*/
    // Add a little randomness so devices don't get sync'd up.
    nextBeacon = millis() + timegap;
    uint8_t r = random(64);
    uint8_t g = random(64);
    uint8_t b = random(64);
    char str[9];
    sprintf(str, "%02x", r);
    sprintf(str + 2, "%02x", g);
    sprintf(str + 4, "%02x", b);
    sprintf(str + 6, "xx");
    strip.setPixelColor(0, strip.Color(r, g, b));
    strip.show();


    irSerial.print(F("0x"));
    irSerial.println(str);
    Serial.print("\n");
    Serial.print("Beacon:");
    Serial.println(str);
  }
}

/*
  // TEA (known to be broken) with all word sizes cut in half (64 bit key, 32 bit blocks)
  // Yes, I'm inviting people to hack this if they want. :-)
  // TODO: Since we're giving up on backward compatability in 2014, should we increase this size?
  void encrypt(uint16_t *v) {
  uint16_t v0 = v[0], v1 = v[1], sum = 0, i;     // set up
  uint16_t delta = 0x9e37;                       // a key schedule constant
  for (i = 0; i < 32; i++) {                     // basic cycle start
    sum += delta;
    v0 += ((v1 << 4) + KEY[0]) ^ (v1 + sum) ^ ((v1 >> 5) + KEY[1]);
    v1 += ((v0 << 4) + KEY[2]) ^ (v0 + sum) ^ ((v0 >> 5) + KEY[3]);
  }                                              // end cycle
  v[0] = v0; v[1] = v1;
  }

  uint16_t getNumMsgs() {
  return (EEPROM.read(MSG_COUNT_ADDR) << 8) + EEPROM.read(MSG_COUNT_ADDR + 1);
  }
*/
/*
  void writeNumMsgs(uint16_t numMsgs) {
  EEPROM.write(MSG_COUNT_ADDR, numMsgs / 256);
  EEPROM.write(MSG_COUNT_ADDR + 1, numMsgs % 256);
  }

  bool isNumMsgsValid(uint16_t numMsgs) {
  return numMsgs < MAX_NUM_MSGS;
  }

  // Writes a pairing code to EEPROM
  int writeEEPROM(unsigned char *guid, uint8_t *msg) {
  char msgStr[9];
  intToStr(msg, msgStr);

  uint16_t numMsgs = getNumMsgs();
  if (!isNumMsgsValid(numMsgs)) {
    Serial.print(F("numMsgs not valid. Setting to 0. Ignore if this is your first pairing."));
    Serial.println(numMsgs);
    // Assume this is the first read of this chip and initialize
    numMsgs = 0;
  }

  int msgAddr;
  unsigned char ndx;
  for (msgAddr = 0; msgAddr < numMsgs * TOTAL_STORAGE_SIZE_MSG; msgAddr += TOTAL_STORAGE_SIZE_MSG) {
    for (ndx = 0; ndx < 8; ndx++) {
      if (guid[ndx] != EEPROM.read(msgAddr + ndx))
        break;
    }
    if (ndx == 8) {
      // Found a match.  Rewrite in case it was wrong before
      break;
    }
  }

  if (ndx != 8) {
    // FIXME This doens't properly stop at 60. It wraps around.
    if (numMsgs > 0 && !isNumMsgsValid(numMsgs)) {
      // The DB is full.  Don't actually create a new entry.
      for (ndx = 0; ndx < 16; ndx++) {
        // Randy Quaid is my hero.
        EEPROM.write(msgAddr + ndx, "SHITTERS FULL..."[ndx]);
      }
      return msgAddr;
    }
    else {
      numMsgs++;
    }
  }

  for (ndx = 0; ndx < 8; ndx++) {
    EEPROM.write(msgAddr + ndx, guid[ndx]);
    EEPROM.write(msgAddr + 8 + ndx, msgStr[ndx]);
  }
  writeNumMsgs(numMsgs);
  return msgAddr;
  }
*/

// This is our receive buffer, for data we pull out of the
// IRSerial library.  This is _NOT_ the buffer the IRSerial
// library is using to receive bytes into.
// Our buffer only needs to be big enough to hold a staza
// to process.  Right now (2014) that's 12 bytes.  I'm over-sizing
// 'cuz why not?
#define RX_BUF_SIZE 32
unsigned char rxBuf[RX_BUF_SIZE];
unsigned char head;

// Increments a pointer into rxBuf, wrapping as appropriate.
unsigned char inc(unsigned char *p) {
  unsigned char q = *p;
  *p = (*p + 1) % RX_BUF_SIZE;
  return q;
}

// Returns the character in rxBuf[] that is p bytes offset from head.
// Deals with wrapping.  You'll probably want to pass a negative
// number as p.
unsigned char rxBufNdx(unsigned char p) {
  return rxBuf[(head + p) % RX_BUF_SIZE];
}

// Turns a 4 byte int (represented here as an array of bytes)
// into a "modified HEX" string.  tr/0-9a-f/A-P/   Makes it
// easier to send in morse code.
void intToStr(uint8_t *src, char *dst) {
  for (unsigned char ndx = 0; ndx < 8; ndx++) {
    dst[ndx] = ((src[ndx >> 1] >> (ndx % 2 ? 0 : 4)) & 0x0F) + 'A';
  }
  dst[8] = '\0';
}

void writeWord(uint8_t *buf) {
  char str[9];
  intToStr(buf, str);
  irSerial.println(str);
}

/* Processes the received buffer, pulls the 8 character "modified HEX"
   out of rxBuf[] (head points at the next byte after the end) and packs it into a
   4 byte array *packedBuf.  If provided, the original 8 "hex" characters
   are also copied into *strDst.
   Messages are of the form:   m/(0[xyab])([A-Z0-9]{8})\r\n/
   $1 is the header and specifies which message it is.
     0x = Alice's GUID beacon  (Alice -> Bob)
     0y = Bob's encrypted reply to Alice's GUID beacon  (Bob -> Alice)
     0a = Bob's GUID (Bob -> Alice, sent immediately after 0y)
     0b = Alice's encrypted reply to Bob's GUID  (Alice -> Bob)
     0w = Message from DarkNet Agent after you've solved the 6 part silk screen crypto
*/
unsigned char readWordFromBuf(uint8_t *packedBuf, unsigned char *strDst = 0) {
  // head points to the next character after the \r\n at the end
  // of our received bytes.  So head-10 points to the beginning of
  // our message, but it's a circular buffer, so we have to wrap.
  unsigned char rxNdx = (head - 10) % RX_BUF_SIZE;

  for (unsigned char ndx = 0; ndx < 8; ndx++, inc(&rxNdx)) {
    unsigned char packedPtr = ndx >> 1;  // index into *packedBuf
    unsigned char cur = rxBuf[rxNdx]; // current "HEX" character

    // Convert from our modified HEX into the actual nibble value.
    if (cur >= 'A' && cur <= 'P') {
      cur -= 'A';
    } else if (cur >= 'Q' && cur <= 'Z') {
      cur -= 'Q';
    } else if (cur >= '0' && cur <= '9') {
      cur = cur - '0' + 6;
    } else {
      Serial.print(F("readWordFromBuf() line noise: "));
      Serial.println(cur);
      return 0;  // Line noise.  Return and wait for the next oneo.
    }
    packedBuf[packedPtr] <<= 4;  // Shift up the previous nibble, filling with zeros
    packedBuf[packedPtr] |= (cur & 0x0F); // Add in the current nibble

    // If provided, also copy rxBuf into *strDst.
    if (strDst) {
      *(strDst++) = rxBuf[rxNdx];
    }
  }
  return 1;
}

unsigned char isValidWord() {
  // Check for valid framing.
  if (rxBufNdx(-1) != '\n' || rxBufNdx(-2) != '\r' || rxBufNdx(-12) != '0') {
    // Probably in the middle of receiving, nothing wrong.
    // Don't log anything, just return.
    return false;
  }

  // We have a good framing. Future failures will be reported.
  char c = rxBufNdx(-11);
  if (c != 'x' && c != 'y' && c != 'a' && c != 'b') {
    Serial.println(F("Bad rx header: "));
    Serial.println(c);
    return false;
  }
  for (int i = -10; i < -2; i++) {
    c = rxBufNdx(i);

    // If it's not a letter and not a number
    if (!(c >= 'a' && c <= 'z') && !(c >= 'A' && c <= 'Z') && !(c >= '0' && c <= '9')) {
      Serial.println(F("Bad rx data: "));
      Serial.println(i);
      Serial.println(F(" "));
      Serial.println(c);
      return false;
    }
  }
  return true;
}

// Reads more characters from the IR and processes them as they come in.
// This differs from processIR() below in that it waits 5000ms for a message
// to come in, rather than returning immediately.  So only call this if
// you're already in the middle of an exchange and know you want to wait.
unsigned char readWordFromIR() {
  head = 0;
  unsigned long start = millis();
  while (millis() - start < 5000) {  // koop for no more than 5 seconds
    if (!irSerial.available())
      continue;
    unsigned char c = irSerial.read();
    rxBuf[head] = c;
    head = (head + 1) % RX_BUF_SIZE;
    if (isValidWord())
      return 1;
  }
  return 0;
}
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
void loop()
{
  switch (current_effect) {
    case 0: NeoEffect_portal (colorsetnum, colorset, 200); break;
    case 1: NeoEffect_spider (colorsetnum, colorset, 100); break;
    case 2: NeoEffect_spider2(colorsetnum, colorset, 50);  break;
    case 3: NeoEffect_cylon  (colorsetnum, colorset, 200);  break;
    case 4: NeoEffect_cylon2 (colorsetnum, colorset, 200);  break;
  }
  if (!debouncedButtonState) {
    debouncedButtonState = 1;
    current_effect = (current_effect + 1) % numeffects;
  }
  Serial.print("Effect = ");
  Serial.print("\t");
  Serial.println(current_effect);
}

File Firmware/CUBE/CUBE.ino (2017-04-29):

/*
 * IRremote: IRrecvDemo - demonstrates receiving IR codes with IRrecv
 * An IR detector/demodulator must be connected to the input RECV_PIN.
 * Version 0.1 July, 2009
 * Copyright 2009 Ken Shirriff
 * http://arcfn.com
 */
#include <IRremote.h>
#include <Adafruit_NeoPixel.h>

#define PIN 7
#define NumberLED 10

int RECV_PIN = 8;
int buttonVal;

int colorState = 0;

boolean fadeState = false;

int rainbowFlag = 0;

float truRed, truBlue, truGreen = 0;
float redVal, greenVal, blueVal = 0; //value between 0-255 for Reg Green Blue values
float lumi = 100;  //value between 1-100 for luminocity 

IRrecv irrecv(RECV_PIN);
decode_results results;

// Parameter 1 = number of pixels in strip
// Parameter 2 = pin number (most are valid)
// Parameter 3 = pixel type flags, add together as needed:
//   NEO_RGB     Pixels are wired for RGB bitstream
//   NEO_GRB     Pixels are wired for GRB bitstream
//   NEO_KHZ400  400 KHz bitstream (e.g. FLORA pixels)
//   NEO_KHZ800  800 KHz bitstream (e.g. High Density LED strip)
Adafruit_NeoPixel strip = Adafruit_NeoPixel(NumberLED, PIN, NEO_GRB + NEO_KHZ800);

long previousMillis = 0;        // will store last time strip was updated
long interval = 5000;           // interval at which color will stay at that color (milliseconds)
unsigned long currentMillis;
///////////////////////////////////////////////////////////
void setup()
{
  //pinMode(10, OUTPUT);//power and GND for IR Receiver
  //pinMode(9, OUTPUT);
  //digitalWrite(10, LOW);
  //digitalWrite(9, HIGH);
  
  strip.begin();
  strip.show();
  Serial.begin(9600);
  
  irrecv.enableIRIn(); // Start the receiver
  Serial.println("waiting...");
}  
/////////////////////////////////////////////////////////////////
void loop()
{
checkButtonPress();
}
//////////////////////////////////////////////////////////////////
void checkButtonPress()
{
  rainbowFlag = 0;
  if (irrecv.decode(&results)) 
  {
        if(results.value != 4294967295 || 0){
        buttonVal = results.value;
        buttonVal = abs(buttonVal);
  }
  checkButton();    
     
                            
  irrecv.resume(); // Receive the next value
  }
}
//////////////////////////////////////////////////////////////////
void checkButton()
{
  rainbowFlag = 0;
  if(buttonVal == 24481)//Up Arrow
  { 
      lumi+=10;
      if(lumi > 100)
      lumi = 100;
      delay(150);
      //Serial.println(lumi);
      
      redVal = truRed * (lumi/100); //calculate luminocity values
      greenVal = truGreen * (lumi/100);
      blueVal = truBlue * (lumi/100);
    
      fill(strip.Color((int)redVal, (int)greenVal, (int)blueVal), 50);
  }   
  if(buttonVal == 255)//Down Arrow
  {
      lumi-=10;
      if(lumi < 0)
      lumi = 0;
      delay(150);
      //Serial.println(lumi);
      
      redVal = truRed * (lumi/100); //calculate luminocity values
      greenVal = truGreen * (lumi/100);
      blueVal = truBlue * (lumi/100);
      
      fill(strip.Color((int)redVal, (int)greenVal, (int)blueVal), 50);
  }
  if(buttonVal == 4335)//Left Arrow
  {
      --colorState;
      if(colorState < 0)
      colorState = 7;
      delay(150);
      checkColor();
  }       
  if(buttonVal == 32641)// Right Arrow
  {
      ++colorState;
      if(colorState > 7)
      colorState = 0;
      delay(150);
      checkColor();
  }   
  if(buttonVal == 0xFF906F)//Red Button
  {
    rainbowFlag = 1;
      rainbow(100);
  } 
  if(buttonVal == 30855)//B Button
  { 
    fadeState = !fadeState;
    delay(150);
    Serial.println(fadeState);
  }
  if(buttonVal == 22695)//C Button
  {
    rainbowFlag = 1;
      rainbowCycle(50);
  }  
  if(buttonVal == 10201)//Power Button
  {
      fill(strip.Color(0, 0, 0), 0);//Off
  }    
  if(buttonVal == 8415)//Center Button
  {
     truRed = 255;
     truGreen = 255;
     truBlue = 255;
      redVal = truRed * (lumi/100); //calculate luminocity values
      greenVal = truGreen * (lumi/100);
      blueVal = truBlue * (lumi/100);
      fill(strip.Color((int)redVal, (int)greenVal, (int)blueVal), 0); //WHITE
  }

}
//////////////////////////////////////////////////////////////
void checkColor()
{
if(colorState == 0)//Pink
{
     truRed = 255;
     truGreen = 0;
     truBlue = 127;
      redVal = truRed * (lumi/100); //calculate luminocity values
      greenVal = truGreen * (lumi/100);
      blueVal = truBlue * (lumi/100);
      if(fadeState == false)
        fill(strip.Color((int)redVal, (int)greenVal, (int)blueVal), 0);
      if(fadeState == true)
        colorWipe(strip.Color((int)redVal, (int)greenVal, (int)blueVal), 100); 
}
if(colorState == 1)// Red
{
     truRed = 255;
     truGreen = 0;
     truBlue = 0;
      redVal = truRed * (lumi/100); //calculate luminocity values
      greenVal = truGreen * (lumi/100);
      blueVal = truBlue * (lumi/100);
      if(fadeState == false)
        fill(strip.Color((int)redVal, (int)greenVal, (int)blueVal), 0);
      if(fadeState == true)
        colorWipe(strip.Color((int)redVal, (int)greenVal, (int)blueVal), 100); 
}
if(colorState == 2)//Orange
{
     truRed = 255;
     truGreen = 127;
     truBlue = 0;
      redVal = truRed * (lumi/100); //calculate luminocity values
      greenVal = truGreen * (lumi/100);
      blueVal = truBlue * (lumi/100);
      if(fadeState == false)
        fill(strip.Color((int)redVal, (int)greenVal, (int)blueVal), 0);
      if(fadeState == true)
        colorWipe(strip.Color((int)redVal, (int)greenVal, (int)blueVal), 100); 
}
if(colorState == 3)//Yellow
{
     truRed = 127;
     truGreen = 255;
     truBlue = 0;
      redVal = truRed * (lumi/100); //calculate luminocity values
      greenVal = truGreen * (lumi/100);
      blueVal = truBlue * (lumi/100);
      if(fadeState == false)
        fill(strip.Color((int)redVal, (int)greenVal, (int)blueVal), 0);
      if(fadeState == true)
        colorWipe(strip.Color((int)redVal, (int)greenVal, (int)blueVal), 100); 
}
if(colorState == 4)//Green
{
     truRed = 0;
     truGreen = 255;
     truBlue = 0;
      redVal = truRed * (lumi/100); //calculate luminocity values
      greenVal = truGreen * (lumi/100);
      blueVal = truBlue * (lumi/100);
      if(fadeState == false)
        fill(strip.Color((int)redVal, (int)greenVal, (int)blueVal), 0);
      if(fadeState == true)
        colorWipe(strip.Color((int)redVal, (int)greenVal, (int)blueVal), 100); 
}
if(colorState == 5)//Teal
{
     truRed = 0;
     truGreen = 255;
     truBlue = 127;
      redVal = truRed * (lumi/100); //calculate luminocity values
      greenVal = truGreen * (lumi/100);
      blueVal = truBlue * (lumi/100);
      if(fadeState == false)
        fill(strip.Color((int)redVal, (int)greenVal, (int)blueVal), 0);
      if(fadeState == true)
        colorWipe(strip.Color((int)redVal, (int)greenVal, (int)blueVal), 100); 
}
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

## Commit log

2017-03-16 ATMega328 Version
    [Apo Board 2017 ATmega328.brd, Apo Board 2017 ATmega328.sch, Apo Board 2017_large.brd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]
2017-03-28 Adding ATmega328 versions
    [Apo Board 2017 ATmega328_SMD.brd, Apo Board 2017 ATmega328_SMD.sch, Apo Board 2017 ATmega328_SMD_MILLABLE.brd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]
2017-03-31 Power Tests
    [Apo Board 2017 ATmega328_SMD.brd, Apo Board 2017 ATmega328_SMD.sch]
2017-04-04 Added layout with PAM2401, cleanup folders
    [Apo Board 2017 .brd, Apo Board 2017 .sch, Apo Board 2017 ATmega328.brd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]
2017-04-06 Added Deacon board files. finished prelim layout
    [Apo Board 2017 ATmega328SMD_PAM2401.brd, Apo Board 2017 ATmega328SMD_PAM2401.sch, hhv-dcdarknet-display.brd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]
2017-04-07 Final touches before review
    [Apo Board 2017 ATmega328SMD_PAM2401.brd, Apo Board 2017 ATmega328SMD_PAM2401.sch]
2017-04-07 Fixing Natural Jumper and few moonier text tweaks
    [Apo Board 2017 ATmega328SMD_PAM2401.brd]
2017-04-08 increased +5v trace width, moved all power traces to top layer, added a fair amount of sitching vias
    [Apo Board 2017 ATmega328SMD_PAM2401.brd, Apo Board 2017 ATmega328SMD_PAM2401.sch]
2017-04-08 Adding testbed
    [Apo Board 2017_PB.brd, Apo Board 2017_PB.sch]
2017-04-10 Final version for Prototypes V0.1 and GERBERS
    [Apo Board 2017 ATmega328SMD_PAM2401.GBL, Apo Board 2017 ATmega328SMD_PAM2401.GBO, Apo Board 2017 ATmega328SMD_PAM2401.GBS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]
2017-04-10 Final version ordered for photos V0.1
    [Apo Board 2017 ATmega328SMD_PAM2401.GBL, Apo Board 2017 ATmega328SMD_PAM2401.GBO, Apo Board 2017 ATmega328SMD_PAM2401.GBS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]
2017-04-11 V0.2 Prototype and GERBERS
    Added Kit footprints, updated silk, charged mounting holes, Named
    board, added year,
    [Apo Board 2017 ATmega328SMD_PAM2401.GBL, Apo Board 2017 ATmega328SMD_PAM2401.GBO, Apo Board 2017 ATmega328SMD_PAM2401.GBS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]
2017-04-11 Adding PAM_Tester board
    [PAM2401_Tester.brd, PAM2401_Tester.sch]
2017-04-13 Cleanup and adding Spec7er's code
    [Apo Board 2017 ATmega328SMD_PAM2401.GBL, Apo Board 2017 ATmega328SMD_PAM2401.GBO, Apo Board 2017 ATmega328SMD_PAM2401.GBS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]
2017-04-18 Updating Battery footprint
    [Apo Board 2017 ATmega328SMD_PAM2401.brd, Apo Board 2017 ATmega328SMD_PAM2401.sch]
2017-04-22 Updating Code to match photo PCBs
2017-04-22 Adding V0.3 PCB
    [ApoBoard_2017_V0_3.brd, ApoBoard_2017_V0_3.sch]
2017-04-25 V1.0 Final version ordered
    [Apo Board 2017 ATmega328SMD_PAM2401.brd, Apo Board 2017 ATmega328SMD_PAM2401.sch, ApoBoard_2017_V0_3.brd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]
2017-04-29 multi effects switch. 5 simple effects so far.
2017-05-04 button debounce. merged code.
2017-05-05 Added Portal 2 animation, can't get button to work
2017-05-05 Revision of button debounce and merged code... did not have a setup to test with since I left it at SSD but it was working for me. IR still in process.
2017-05-05 merged & fixed & verifed button code and new effects
2017-05-07 Adding lots of color sets
    Cleaned up and added close to final color sets, Cleaned up spider
    animations, Added campmate code to put on boards for campmates after
    beta test so they have all modes and colors. Randomizing colorists as
    we increment through the animations.
2017-05-07 gene exchange + master programming mode VS 1 - some bugs still but basic function. Collect up to 20 genes. Any device can be put into PROGRAMMER mode by holding down button for 10+ seconds. In PROGRA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
    [IRSerial-2014.cpp]
2017-05-08 EEPROM working now. Stores 20 genes with CRC16. Improved stack/heap use a little. Fixed crazy flashing in PROGRAMMER mode.
    [ApoBoard_JoelsCodeDreamV03.ino]
2017-05-10 fix v2 fuckup due to poor git management by specter restored from 1171ec4
    [IRSerial-2014.cpp]
2017-05-10 fixed bug in debounce causeing phantom keypress
    [ApoBoard_JoelsCodeDreamV03.ino]
2017-05-11 Updating Testbed - almost finished
    [Apo Board 2017_PB_MILLABLE.brd, Apo Board 2017_PB_MILLABLE.sch, Apo Board 2017_PM.brd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]
2017-05-12 Added utilities. Now anyone with a serial connection can change eeprom values, dump eeprom, and reset eeprom. Send ? to device over serial to see the help menu
    [ApoBoard_JoelsCodeDreamV03.ino]
2017-05-12 Pogo Bed finished.
    Finished making pogoed programming and testing fixture. Moving to
    Hardware Folder
    [Apo Board 2017_PB.brd, Apo Board 2017_PB.sch, Apo Board 2017_PB_MILLABLE.brd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]
2017-05-13 Fixed 'learn gene' bug causing multiple genes of same type being stored. Proper gene function is confirmed on SPECTER's side. Also, button need only be pressed for less than 1second to 'learn' new ge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
    [ApoBoard_JoelsCodeDreamV03.ino]
2017-05-14 Effect 13 , pacman's revenge, a short film done in 10 leds.
    [ApoBoard_JoelsCodeDreamV03.ino]
2017-05-17 refining bottom layer of testbed
    [Apo Board 2017_PB.brd, Apo Board 2017_PB.sch]
2017-05-23 added notes about atmega328 fuses
2017-05-28 fixes to moar effects + more progmem
    [ApoBoard_JoelsCodeDreamV03.ino]
2017-05-28 Adding testbed success LED to firmware
    LED on A5 now blinks in setup() to visually verify a successful upload
    of the firmware.
2017-05-29 Effects bugfixes a. Much IR debug enabled - I will comment out later srry.
    [ApoBoard_JoelsCodeDreamV03.ino, IRSerial-2014.cpp]
2017-05-29 remove pac eye. Fix eye blink. mostly eyes really.
    [ApoBoard_JoelsCodeDreamV03.ino]
2017-05-29 fixed rollover. fixed fill bug in terminal. poc for mating dance
    [ApoBoard_JoelsCodeDreamV03.ino]
2017-05-31 many last minute bug fixes to timing, mating=green, wrap(in,limit) and others
    [ApoBoard_JoelsCodeDreamV03.ino]
2017-05-31 minor last minute bugfixes... to be honest I can't remember
    [ApoBoard_JoelsCodeDreamV03.ino]

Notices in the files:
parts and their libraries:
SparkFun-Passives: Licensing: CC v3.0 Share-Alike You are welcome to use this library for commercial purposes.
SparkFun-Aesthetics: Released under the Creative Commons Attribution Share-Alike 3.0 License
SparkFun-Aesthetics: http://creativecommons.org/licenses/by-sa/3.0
